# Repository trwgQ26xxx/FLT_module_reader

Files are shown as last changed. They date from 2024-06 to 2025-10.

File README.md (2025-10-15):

# Fiat Lancia Tester \ Alfa Romeo Tester \ Check Up 1 module reader

Dedicated module reader for FLT\ART\CU-1 ROMs archiving.

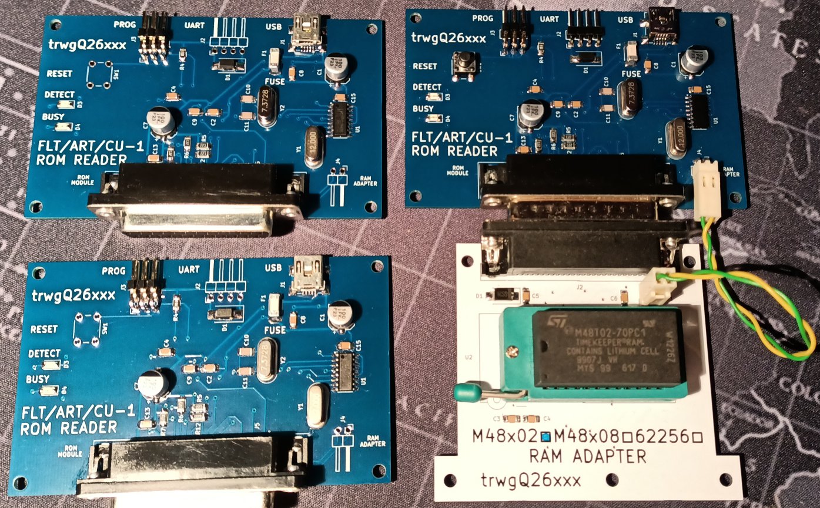
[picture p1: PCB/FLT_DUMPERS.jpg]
FLT_DUMPERS

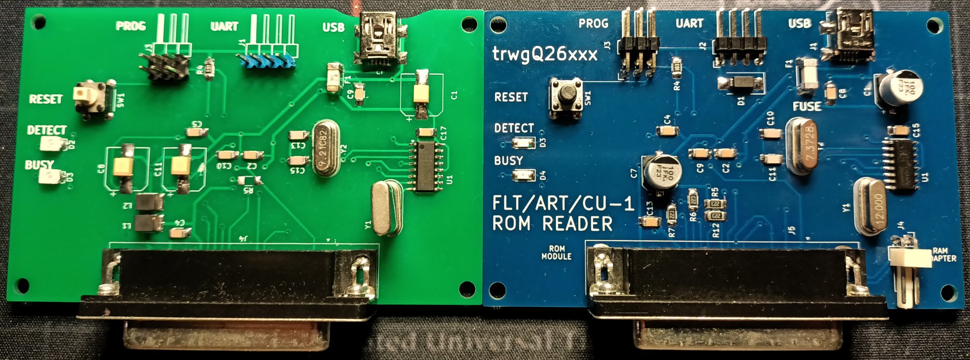
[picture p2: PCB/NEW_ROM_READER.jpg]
NEW_ROM_READER


# Disclaimer

I do not consent to the use of all or part of the project for commercial purposes!

Nie wyrażam zgody na wykorzystanie całości bądź części projektu w celach zarobkowych!

# License

Shield: [][cc-by-nc-sa]

This work is licensed under a
[Creative Commons Attribution-NonCommercial-ShareAlike 4.0 International License][cc-by-nc-sa].

[][cc-by-nc-sa]

[cc-by-nc-sa]: http://creativecommons.org/licenses/by-nc-sa/4.0/
[cc-by-nc-sa-image]: https://licensebuttons.net/l/by-nc-sa/4.0/88x31.png
[cc-by-nc-sa-shield]: https://img.shields.io/badge/License-CC%20BY--NC--SA%204.0-lightgrey.svg

# Directories organization

- **firmware** - MCU firmware, written in C.
- **pc_software** - PC software, written in Python.
- **PCB** - PCB project, prepared in KiCad version 8.0.1.
- **DS** - data sheets of used components

# Usage

| Windows | Linux | macOS |
| --- | --- | --- |
| reader COM[number] | ./reader /dev/ttyUSB[number] | ./reader /dev/wchusbserial[number] |

For example:

| Windows | Linux | macOS |
| --- | --- | --- |
| reader COM1 | ./reader /dev/ttyUSB0 | ./reader /dev/wchusbserial300 |

where */dev/wchusbserial300* (on macOS), */dev/ttyUSB0* (on Linux) or *COM1* (on Windows) should be actual serial port name of connected ROM reader.

# Basic instructions

1. (optional step) *search_ports* script can be used to identify ROM reader serial port name.

The ROM reader uses the CH340 serial chip, which can be identified by the VID/PID values of 1A86/7523, respectively.

SEARCH_PORTS

2. Connect the ROM reader to the PC. Running the program on a PC without a connected module will result in an error.

NO_MODULE

NO_MODULE_WIN

3. If a module is connected, the reader detects which ROMs are present in the connected module. In this example, we have a module with all three (**ROM A, B, and C**). If at least one ROM is installed (which will always be the case, since ROM B must be present), the program will prompt you to enter a prefix for the files that will be saved on the PC. I entered *M99A_IT* as an example. After confirming by pressing Enter, the ROM data dumping process begins:

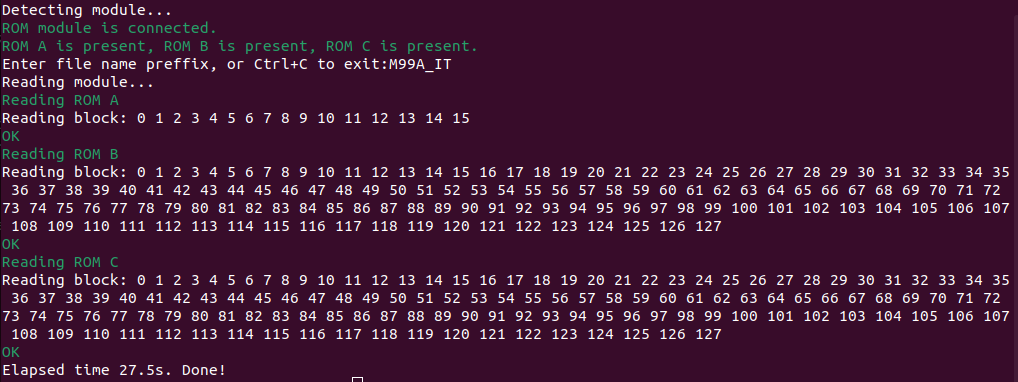
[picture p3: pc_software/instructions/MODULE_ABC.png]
MODULE_ABC


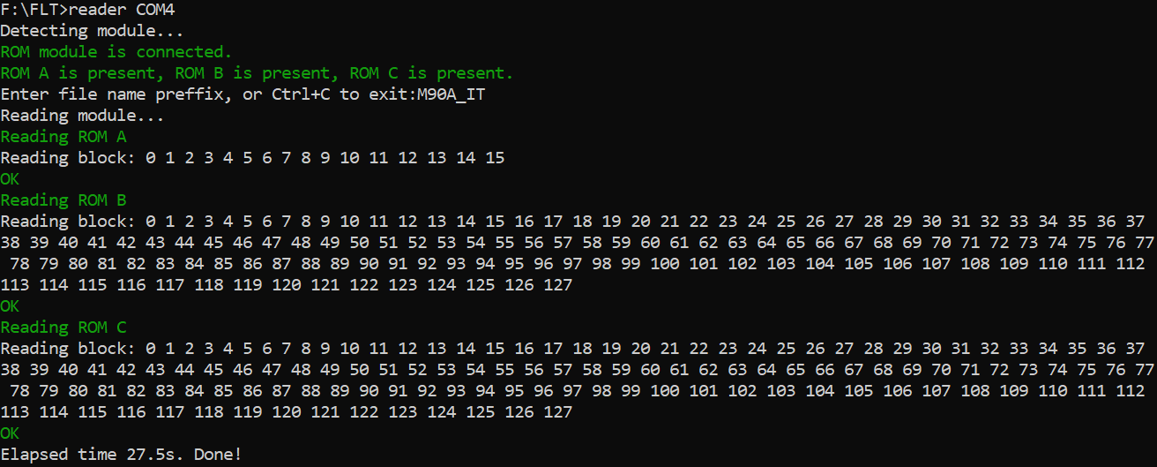
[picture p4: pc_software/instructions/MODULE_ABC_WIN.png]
MODULE_ABC_WIN


4. Data integrity is continuously checked using CRC while downloading individual blocks (each block is 512 bytes). **In most cases, it may be advisable to repeat the dumping operation twice, disconnecting and reconnecting the ROM module to clean the contacts slightly.** Finally, individual files containing the ROM data are saved to the PC:

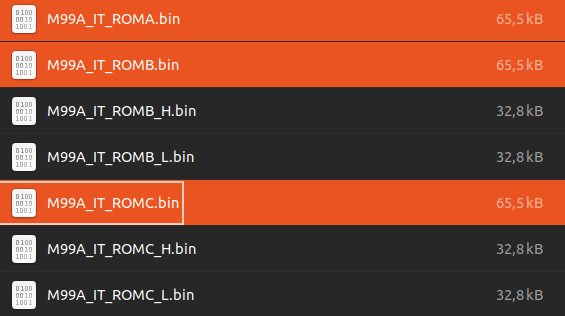
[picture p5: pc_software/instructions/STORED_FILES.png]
STORED_FILES


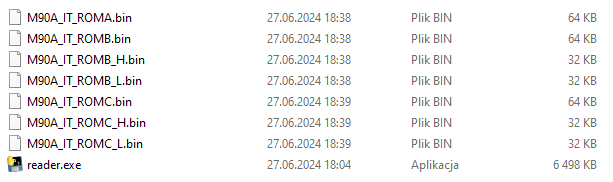
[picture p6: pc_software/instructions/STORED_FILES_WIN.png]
STORED_FILES_WIN


The process is similar for other modules. Here is an example if the module contains only **ROM A and B**:

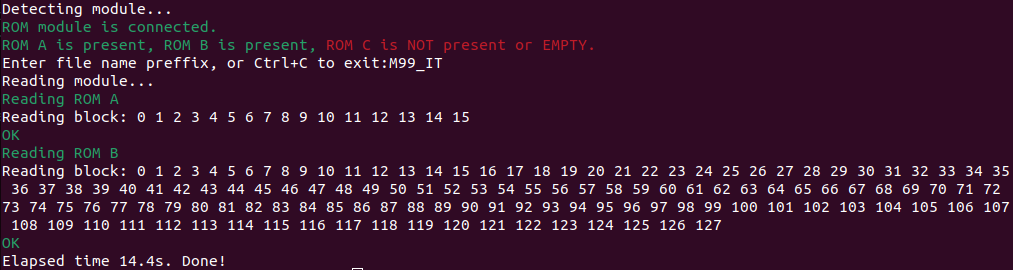
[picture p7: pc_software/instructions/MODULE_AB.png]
MODULE_AB


or **ROM B** only:

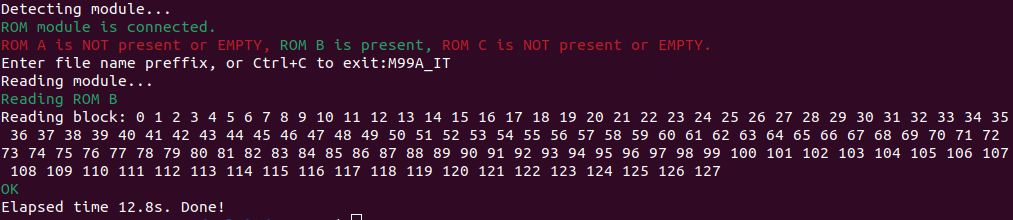
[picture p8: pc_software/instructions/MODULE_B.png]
MODULE_ABC


The program reads the contents of only the ROMs that are present in the module.

# RAM adapter

The RAM adapter is used for SRAM testing. It was primarily constructed to test the M48Z02 (used in FLT/ART) and the M48T02 (used in CU-1). The RAM adapter takes the form of a standard FLT ROM module. Additionally, it requires a connection to a supplementary 2-pin connector with the #WR signal, which is not present on the DSUB-25 connector of the ROM.

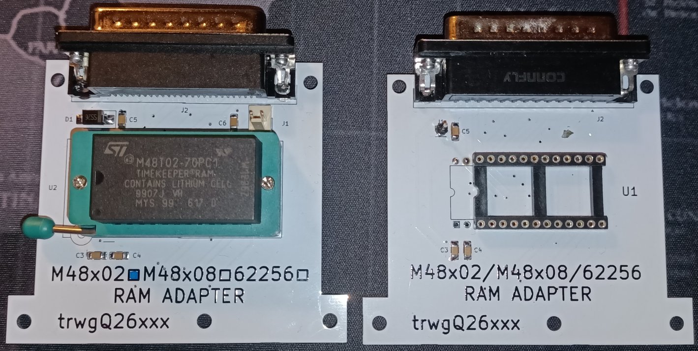
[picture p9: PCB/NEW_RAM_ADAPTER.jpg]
NEW_RAM_ADAPTER


Before usage, the RAM adapter must be configured to the correct RAM variant using solder bridges (SB1 - SB3) on the PCB. The configuration is as follows:

| RAM | Size | SB1 | SB2 | SB3 |
| --- | ---- | --- | --- | --- |
| M48T02, M48T12, M48Z02 and M48Z12 | 2kB | OFF | 1-2 | 1-2 |
| M48T08, M48T18, M48Z08 and M48Z18 | 8kB | OFF | 1-2 | 2-3 |
| 62256 | 32kB | ON | 2-3 | 2-3 |

The supported commands are:

* *RAM_test ram_type serial_port*, for example: ./RAM_test M48T02 /dev/ttyUSB0

This command tests the SRAM battery and SRAM memory. The supported SRAM types (*ram_type*) for this command are:

| *ram_type* | Size | Type |
| --- | --- | --- |
| M48T02 | 2kB | battery-backed SRAM with RTC |
| M48Z02 | 2kB | battery-backed SRAM |
| M48T08 | 8kB | battery-backed SRAM with RTC |
| M48Z08 | 8kB | battery-backed SRAM |
| S62256 | 32kB | SRAM |

RAM_TEST

* *RAM_clock_cmd ram_type command serial_port*, for example ./RAM_clock_cmd M48T02 set /dev/ttyUSB0

Executes an RTC-specific command. The command (*command*) can be:

| *command* | Description |
| --- | --- |
| start | Starts the internal oscillator and enables normal clock operation. |
| stop | Stops the internal oscillator, which saves battery power if the SRAM is left on the shelf for an extended period. |
| set | Sets the current time. |
| reset | Resets all registers, stops the internal oscillator, and sets the time to 0:0:0 on 1-1-2000. |

The supported SRAM types for this command are:

| *ram_type* | Size | Type |
| --- | --- | --- |
| M48T02 | 2kB | battery-backed SRAM with RTC |
| M48T08 | 8kB | battery-backed SRAM with RTC |

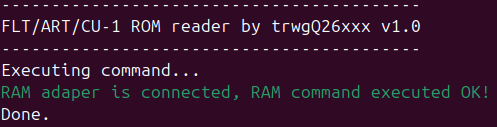
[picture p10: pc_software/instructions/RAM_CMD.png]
RAM_CMD


* *RAM_clock_read ram_type serial_port*, for example ./RAM_clock_read M48T02 /dev/ttyUSB0

Retrieves the time from the SRAM RTC and prints it on the screen in an infinite loop at a rate of twice per second. Use Ctrl-C to stop the execution of this command.

The supported SRAM types for this command are:

| *ram_type* | Size | Type |
| --- | --- | --- |
| M48T02 | 2kB | battery-backed SRAM with RTC |
| M48T08 | 8kB | battery-backed SRAM with RTC |

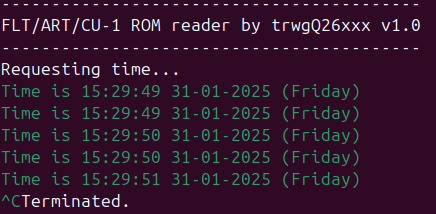
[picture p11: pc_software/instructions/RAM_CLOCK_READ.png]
RAM_CLOCK_READ


# Complete procedure to test battery-backed RAM

1. Use *RAM_test* to check the RAM battery and RAM memory cells.
2. If the RAM has an RTC:

- Execute the *reset command* to reset the RAM clock.

- Execute the *start command** to starts the internal oscillator and enable normal clock operation.

- Execute the *set command* to set the current time.

- Run *RAM_clock_read* to verify both the validity of the time and that it increments. If both conditions are met, the RTC is functioning properly.

# Notes

Atmega64A fusebits should be configured as follows:

| Extended | High | Low |
| --- | --- | --- |
| 0xFE | 0xC9 | 0x1F |

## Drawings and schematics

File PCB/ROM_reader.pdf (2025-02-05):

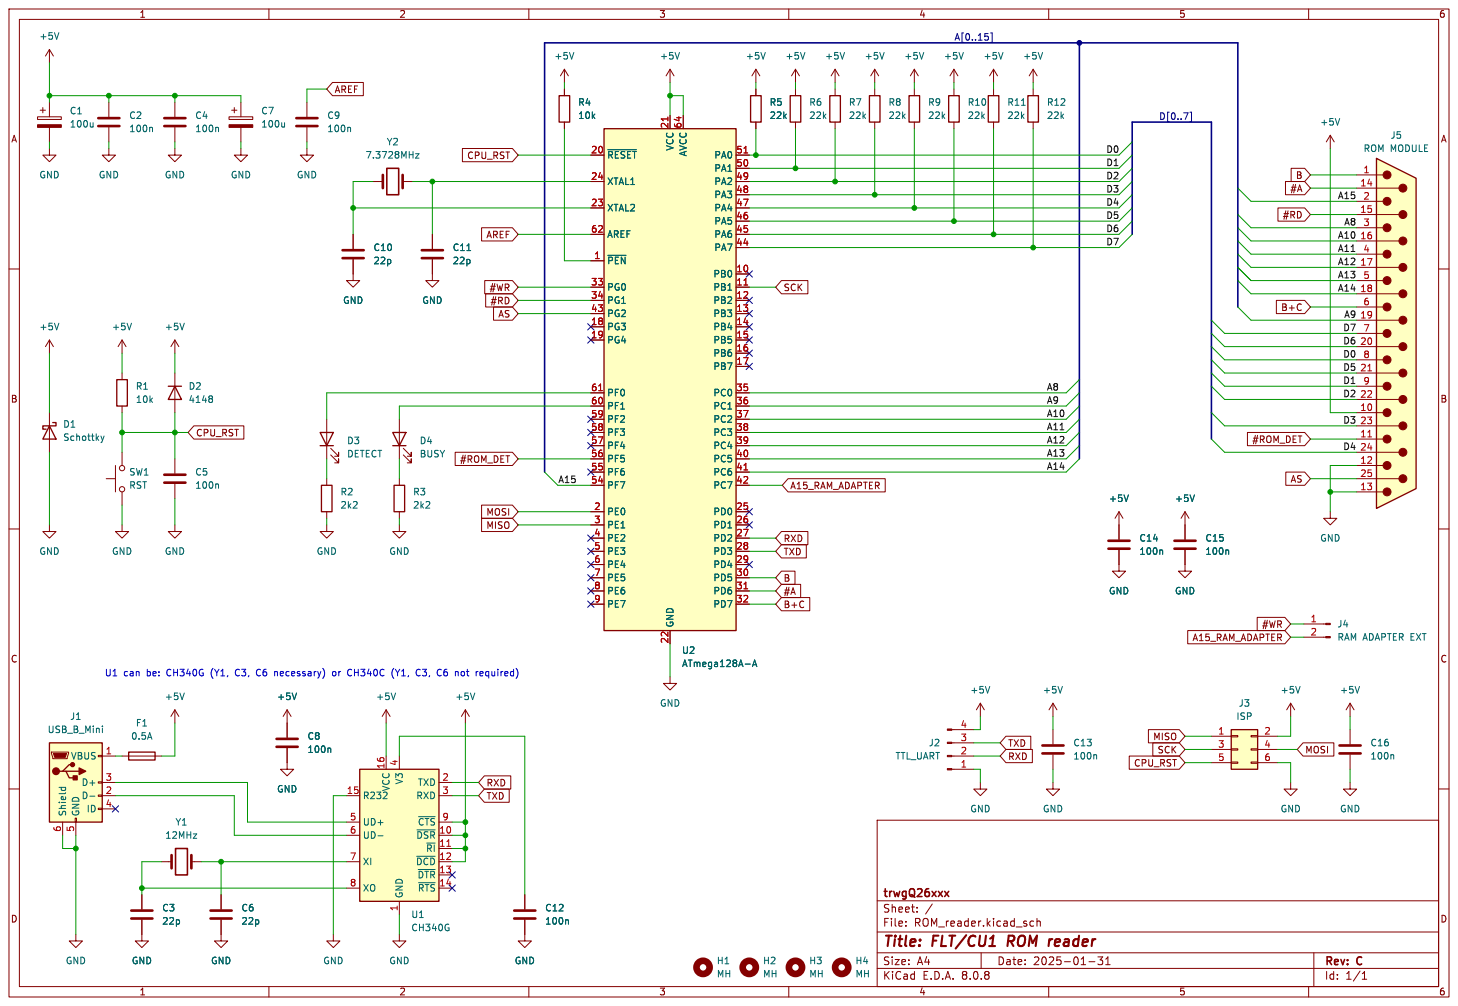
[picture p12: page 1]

1 ~{DSR} 10 ~{RI} 11 ~{DCD} 12 ~{DTR} 13 ~{RTS} 14 R232 15 VCC 16 TXD 2 RXD 3 V3

4 UD+ 5 UD- 6 XI 7 XO 8 ~{CTS}9 U1 CH340G

Id: 1/1 Title: FLT/CU1 ROM reader File: ROM_reader.kicad_sch Sheet: / trwgQ26xxx Y1

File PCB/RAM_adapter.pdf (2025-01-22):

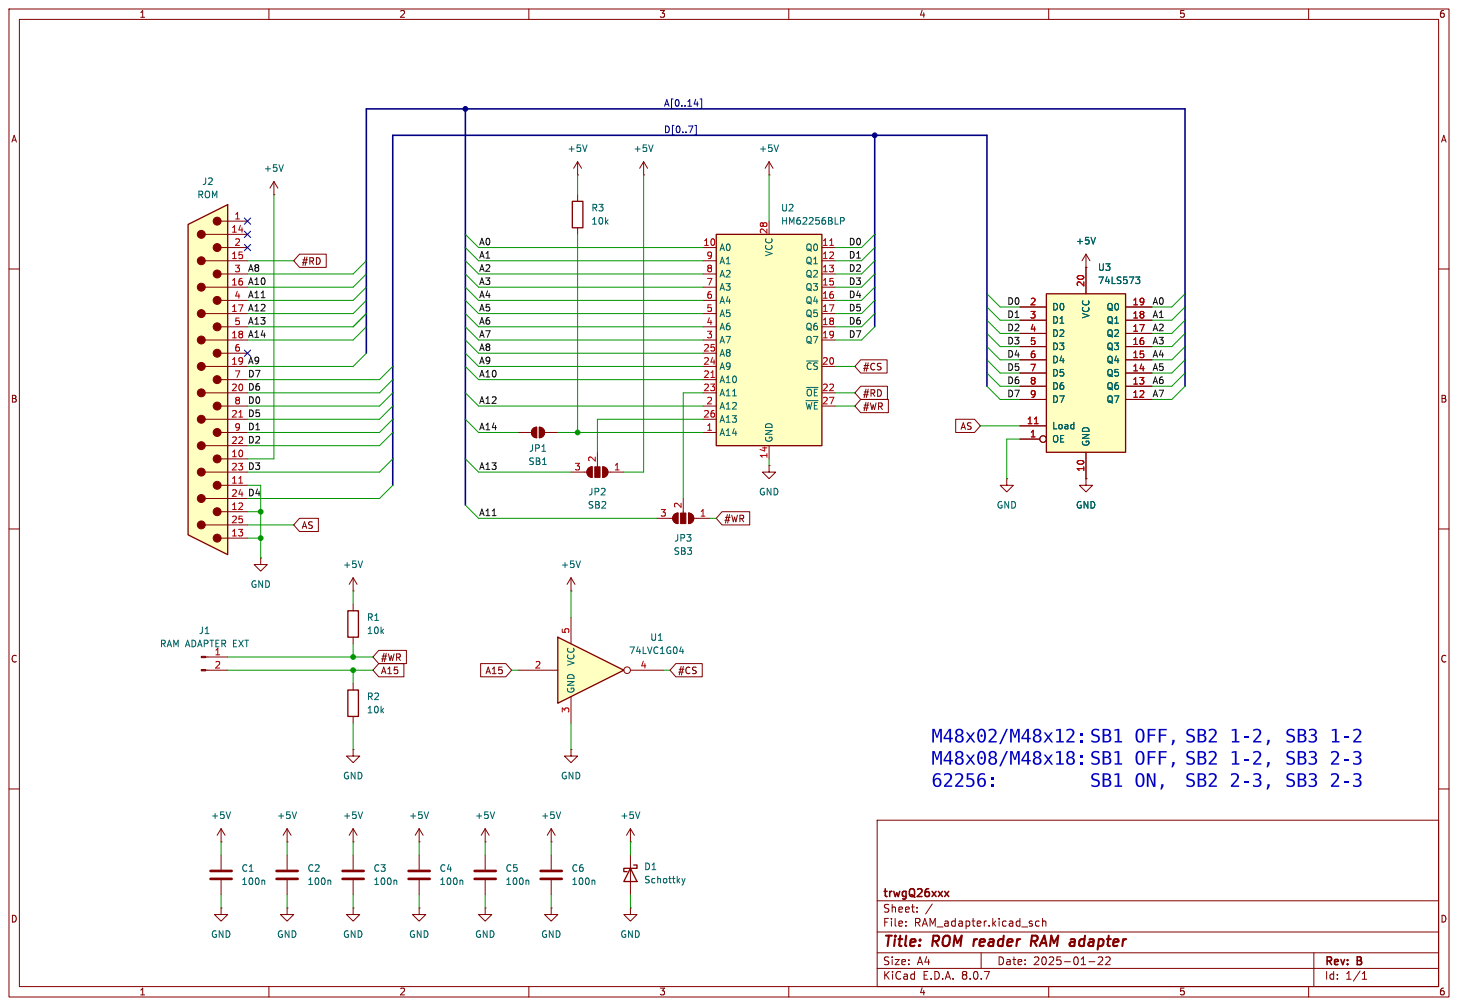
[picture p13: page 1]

Id: 1/1 Title: ROM reader RAM adapter File: RAM_adapter.kicad_sch Sheet: / trwgQ26xxx C6

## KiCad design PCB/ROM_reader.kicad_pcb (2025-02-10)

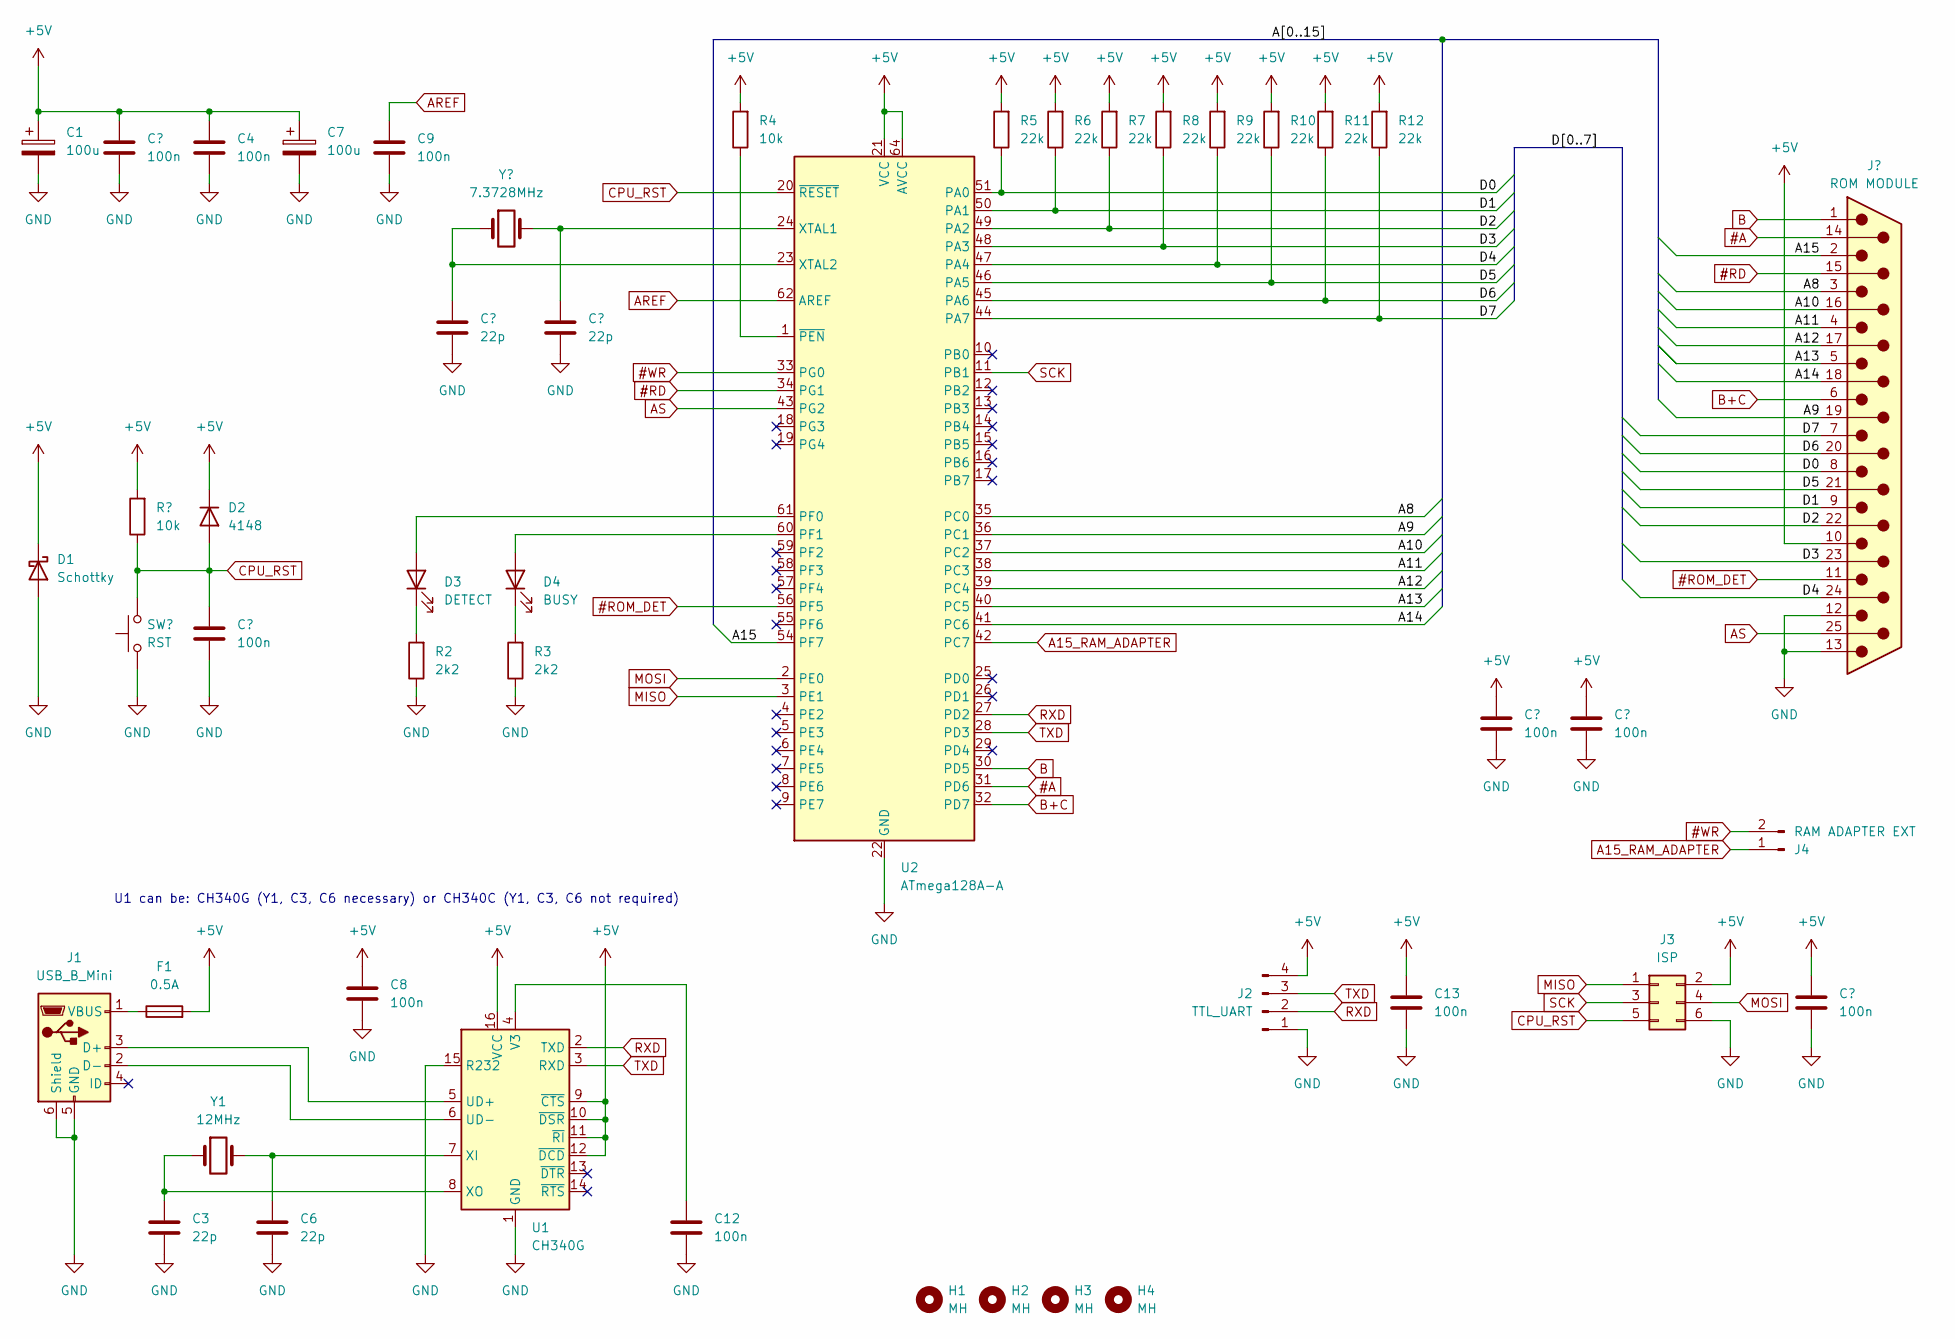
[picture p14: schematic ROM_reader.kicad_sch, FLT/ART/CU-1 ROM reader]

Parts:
C1, C7: 100u; CP_Elec_6.3x7.7
C2, C4, C5, C8, C9, C12, C13, C14, C15, C16: 100n; C_1206_3216Metric_Pad1.33x1.80mm_HandSolder
C3, C6, C10, C11: 22p; C_1206_3216Metric_Pad1.33x1.80mm_HandSolder
D1: Schottky; D_SMB_Handsoldering
D2: 4148; D_SMA_Handsoldering
D3: DETECT; LED_1206_3216Metric_Pad1.42x1.75mm_HandSolder
D4: BUSY; LED_1206_3216Metric_Pad1.42x1.75mm_HandSolder
F1: 0.5A; Fuse_2512_6332Metric_Pad1.52x3.35mm_HandSolder
H1, H2, H3, H4: MH; MountingHole_3.2mm_M3_DIN965
J1: USB_B_Mini; USB_Mini-B_Wuerth_65100516121_Horizontal
J2: TTL_UART; PinHeader_1x04_P2.54mm_Horizontal
J3: ISP; PinHeader_2x03_P2.54mm_Horizontal
J4: RAM ADAPTER EXT; PinHeader_1x02_P2.54mm_Horizontal
J5: ROM MODULE; DSUB-25_Female_Horizontal_P2.77x2.84mm_EdgePinOffset4.94mm_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
R1, R4: 10k; R_1206_3216Metric_Pad1.30x1.75mm_HandSolder
R2, R3: 2k2; R_1206_3216Metric_Pad1.30x1.75mm_HandSolder
R5, R6, R7, R8, R9, R10, R11, R12: 22k; R_1206_3216Metric_Pad1.30x1.75mm_HandSolder
SW1: RST; SW_PUSH_6mm
U1: CH340G; SOIC-16_3.9x9.9mm_P1.27mm
U2: ATmega128A-A; TQFP-64_14x14mm_P0.8mm
Y1: 12MHz; Crystal_HC49-4H_Vertical
Y2: 7.3728MHz; Crystal_HC49-4H_Vertical

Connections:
#A: J5.14, U2.31 (PD6)
#RD: J5.15, U2.34 (PG1)
#ROM_DET: J5.11, U2.56 (PF5)
#WR: J4.2, U2.33 (PG0)
+5V: C1.1, C2.1, C4.1, C7.1, C8.1, C13.1, C14.1, C15.1, C16.1, D1.1 (K), D2.1 (K), F1.2, J2.4, J3.2, J5.10, R1.2, R4.2, R5.2, R6.2, R7.2, R8.2, R9.2, R10.2, R11.2, R12.2, U1.9 (~CTS), U1.10 (~DSR), U1.11 (~RI), U1.12 (~DCD), U1.16 (VCC), U2.21 (VCC), U2.52 (VCC), U2.64 (AVCC)
/A8: J5.3, U2.35 (PC0)
/A9: J5.19, U2.36 (PC1)
/A10: J5.16, U2.37 (PC2)
/A11: J5.4, U2.38 (PC3)
/A12: J5.17, U2.39 (PC4)
/A13: J5.5, U2.40 (PC5)
/A14: J5.18, U2.41 (PC6)
/A15: J5.2, U2.54 (PF7)
/D0: J5.8, R5.1, U2.51 (PA0)
/D1: J5.9, R6.1, U2.50 (PA1)
/D2: J5.22, R7.1, U2.49 (PA2)
/D3: J5.23, R8.1, U2.48 (PA3)
/D4: J5.24, R9.1, U2.47 (PA4)
/D5: J5.21, R10.1, U2.46 (PA5)
/D6: J5.20, R11.1, U2.45 (PA6)
/D7: J5.7, R12.1, U2.44 (PA7)
A15_RAM_ADAPTER: J4.1, U2.42 (PC7)
AREF: C9.1, U2.62 (AREF)
AS: J5.25, U2.43 (PG2)
B: J5.1, U2.30 (PD5)
B+C: J5.6, U2.32 (PD7)
CPU_RST: C5.1, D2.2 (A), J3.5, R1.1, SW1.2, U2.20 (~RESET)
GND: C1.2, C2.2, C3.2, C4.2, C5.2, C6.2, C7.2, C8.2, C9.2, C10.2, C11.2, C12.2, C13.2, C14.2, C15.2, C16.2, D1.2 (A), J1.5 (GND), J1.6 (Shield), J2.1, J3.6, J5.0, J5.12, J5.13, R2.1, R3.1, SW1.1, U1.1 (GND), U1.15 (R232), U2.22 (GND), U2.53 (GND), U2.63 (GND)
MISO: J3.1, U2.3 (PE1)
MOSI: J3.4, U2.2 (PE0)
unnamed: D3.2 (A), U2.61 (PF0)
unnamed: D3.1 (K), R2.2
unnamed: D4.2 (A), U2.60 (PF1)
unnamed: D4.1 (K), R3.2
unnamed: J1.3 (D+), U1.5 (UD+)
unnamed: J1.2 (D-), U1.6 (UD-)
unnamed: F1.1, J1.1 (VBUS)
unnamed: C12.1, U1.4 (V3)
unnamed: C6.1, U1.7 (XI), Y1.2
unnamed: C3.1, U1.8 (XO), Y1.1
unnamed: C11.1, U2.24 (XTAL1), Y2.2
unnamed: C10.1, U2.23 (XTAL2), Y2.1
unnamed: R4.1, U2.1 (~PEN)
RXD: J2.2, U1.2 (TXD), U2.27 (PD2)
SCK: J3.3, U2.11 (PB1)
TXD: J2.3, U1.3 (RXD), U2.28 (PD3)

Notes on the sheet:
U1 can be: CH340G (Y1, C3, C6 necessary) or CH340C (Y1, C3, C6 not required)

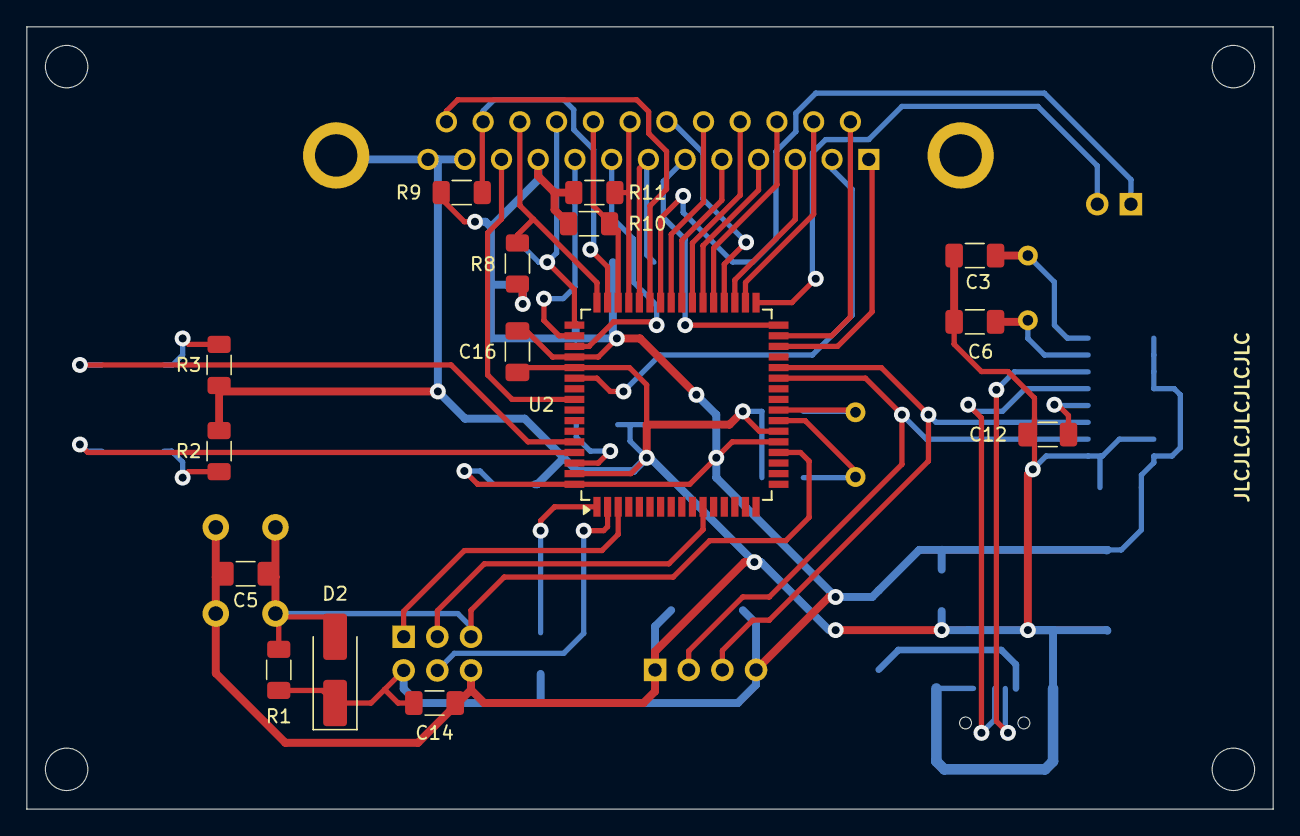
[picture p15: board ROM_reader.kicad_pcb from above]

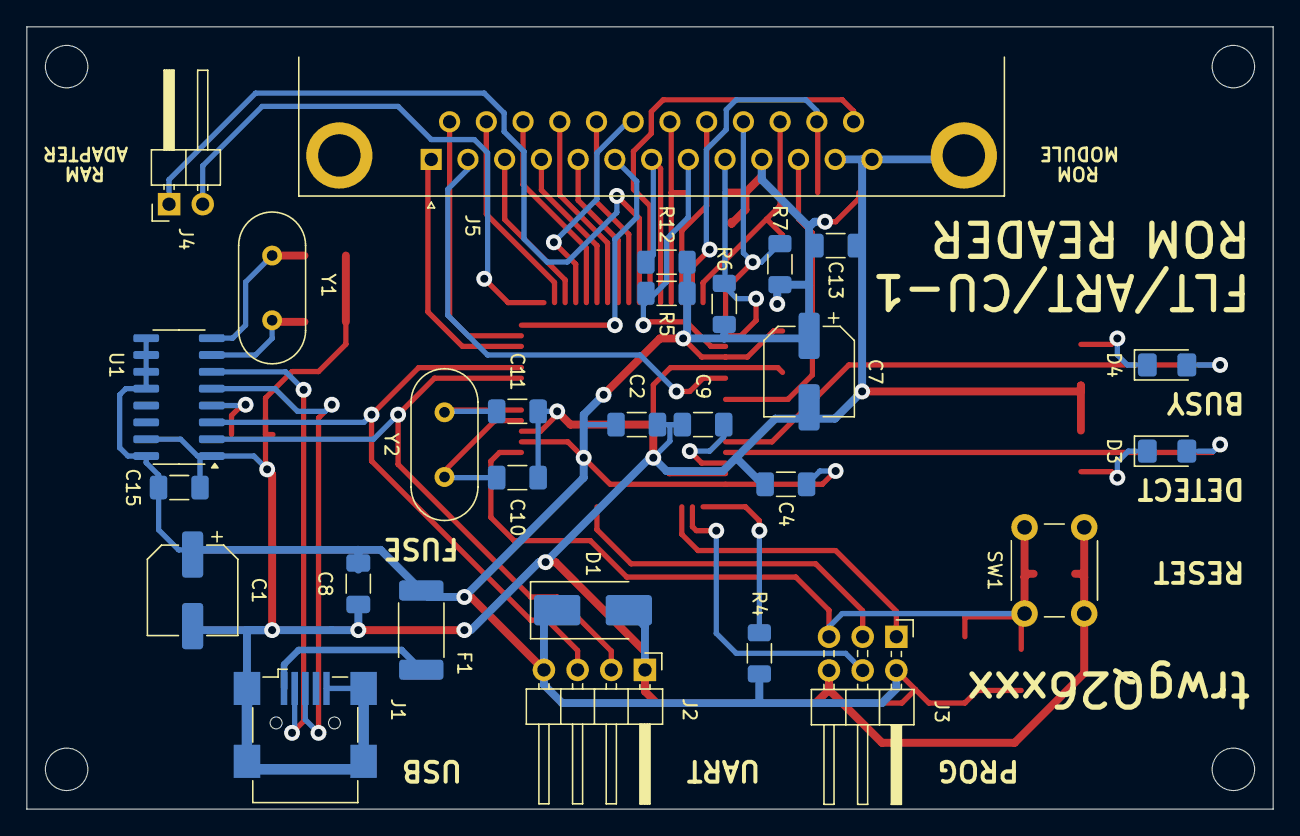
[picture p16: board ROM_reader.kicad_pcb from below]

Board: 2 copper layers, 94.0 x 59.0 mm, 47 parts (28 on the bottom side), 46 nets.

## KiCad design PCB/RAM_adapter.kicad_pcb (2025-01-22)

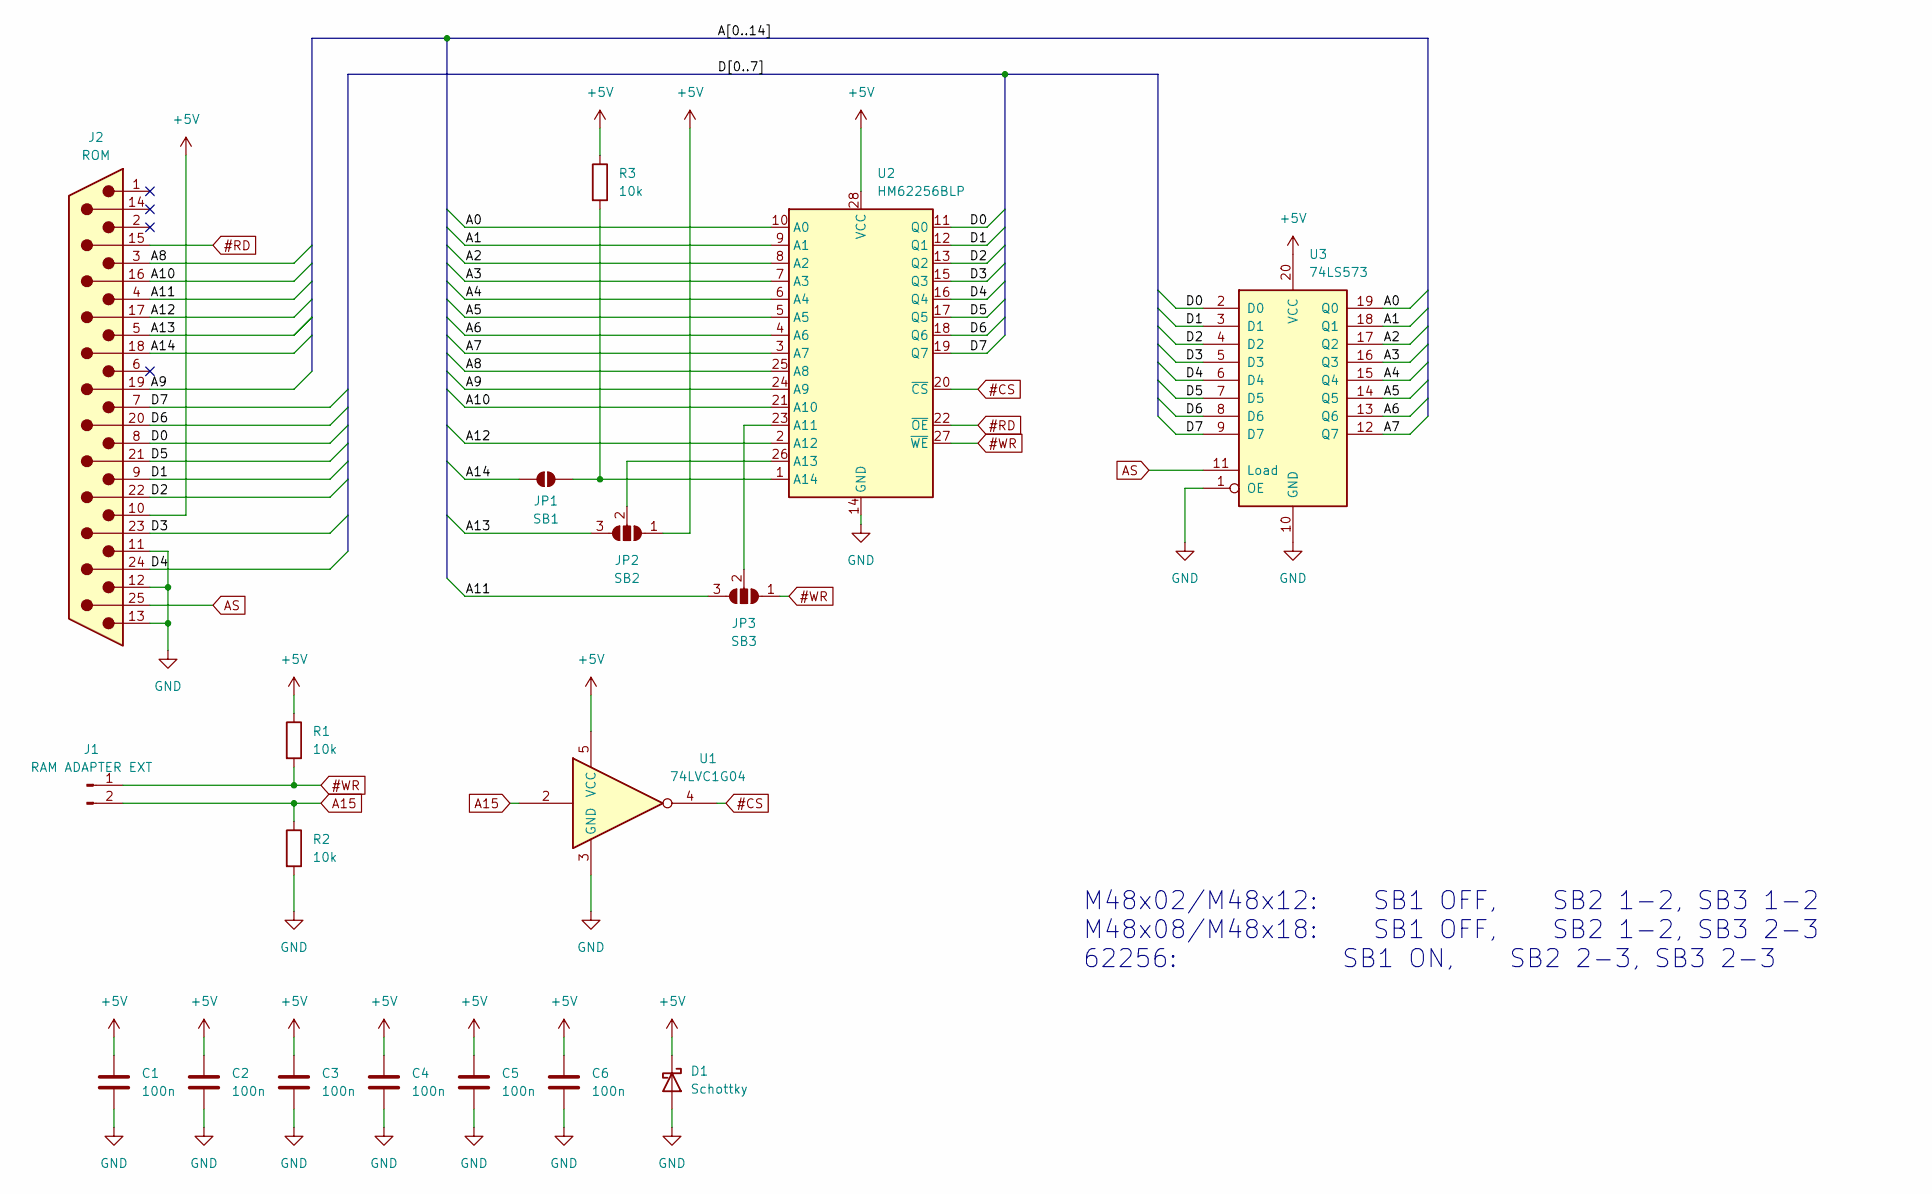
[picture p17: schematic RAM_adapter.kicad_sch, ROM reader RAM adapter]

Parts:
C1, C2, C3, C4, C5, C6: 100n; C_1206_3216Metric_Pad1.33x1.80mm_HandSolder
D1: Schottky; D_SMB_Handsoldering
J1: RAM ADAPTER EXT; PinHeader_1x02_P2.54mm_Vertical
J2: ROM; DSUB-25_Male_Horizontal_P2.77x2.84mm_EdgePinOffset4.94mm_Ho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
JP1: SB1; SolderJumper-2_P1.3mm_Open_RoundedPad1.0x1.5mm
JP2: SB2; SolderJumper-3_P1.3mm_Open_RoundedPad1.0x1.5mm
JP3: SB3; SolderJumper-3_P1.3mm_Open_RoundedPad1.0x1.5mm
R1, R2, R3: 10k; R_1206_3216Metric_Pad1.30x1.75mm_HandSolder
U1: 74LVC1G04; SOT-23-5_HandSoldering
U2: HM62256BLP; DIP_Socket-28_W11.9_W12.7_W15.24_W17.78_W18.5_3M_228-1277-0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
U3: 74LS573; SOIC-20W_7.5x12.8mm_P1.27mm

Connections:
#CS: U1.4, U2.20 (~CS)
#RD: J2.15, U2.22 (~OE)
#WR: J1.1, JP3.1 (A), R1.2, U2.27 (~WE)
+5V: C1.1, C2.1, C3.1, C4.1, C5.1, C6.1, D1.1 (K), J2.10, JP2.1 (A), R1.1, R3.1, U1.5 (VCC), U2.28 (VCC), U3.20 (VCC)
/A0: U2.10 (A0), U3.19 (Q0)
/A1: U2.9 (A1), U3.18 (Q1)
/A2: U2.8 (A2), U3.17 (Q2)
/A3: U2.7 (A3), U3.16 (Q3)
/A4: U2.6 (A4), U3.15 (Q4)
/A5: U2.5 (A5), U3.14 (Q5)
/A6: U2.4 (A6), U3.13 (Q6)
/A7: U2.3 (A7), U3.12 (Q7)
/A8: J2.3, U2.25 (A8)
/A9: J2.19, U2.24 (A9)
/A10: J2.16, U2.21 (A10)
/A11: J2.4, JP3.3 (B)
/A12: J2.17, U2.2 (A12)
/A13: J2.5, JP2.3 (B)
/A14: J2.18, JP1.2 (B)
/D0: J2.8, U2.11 (Q0), U3.2 (D0)
/D1: J2.9, U2.12 (Q1), U3.3 (D1)
/D2: J2.22, U2.13 (Q2), U3.4 (D2)
/D3: J2.23, U2.15 (Q3), U3.5 (D3)
/D4: J2.24, U2.16 (Q4), U3.6 (D4)
/D5: J2.21, U2.17 (Q5), U3.7 (D5)
/D6: J2.20, U2.18 (Q6), U3.8 (D6)
/D7: J2.7, U2.19 (Q7), U3.9 (D7)
A15: J1.2, R2.1, U1.2
AS: J2.25, U3.11 (Load)
GND: C1.2, C2.2, C3.2, C4.2, C5.2, C6.2, D1.2 (A), J2.11, J2.12, J2.13, R2.2, U1.3 (GND), U2.14 (GND), U3.1 (OE), U3.10 (GND)
unnamed: JP1.1 (A), R3.2, U2.1 (A14)
unnamed: JP2.2 (C), U2.26 (A13)
unnamed: JP3.2 (C), U2.23 (A11)

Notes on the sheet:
M48x02/M48x12: SB1 OFF, SB2 1-2, SB3 1-2 M48x08/M48x18: SB1 OFF, SB2 1-2, SB3 2-3 62256: SB1 ON, SB2 2-3, SB3 2-3

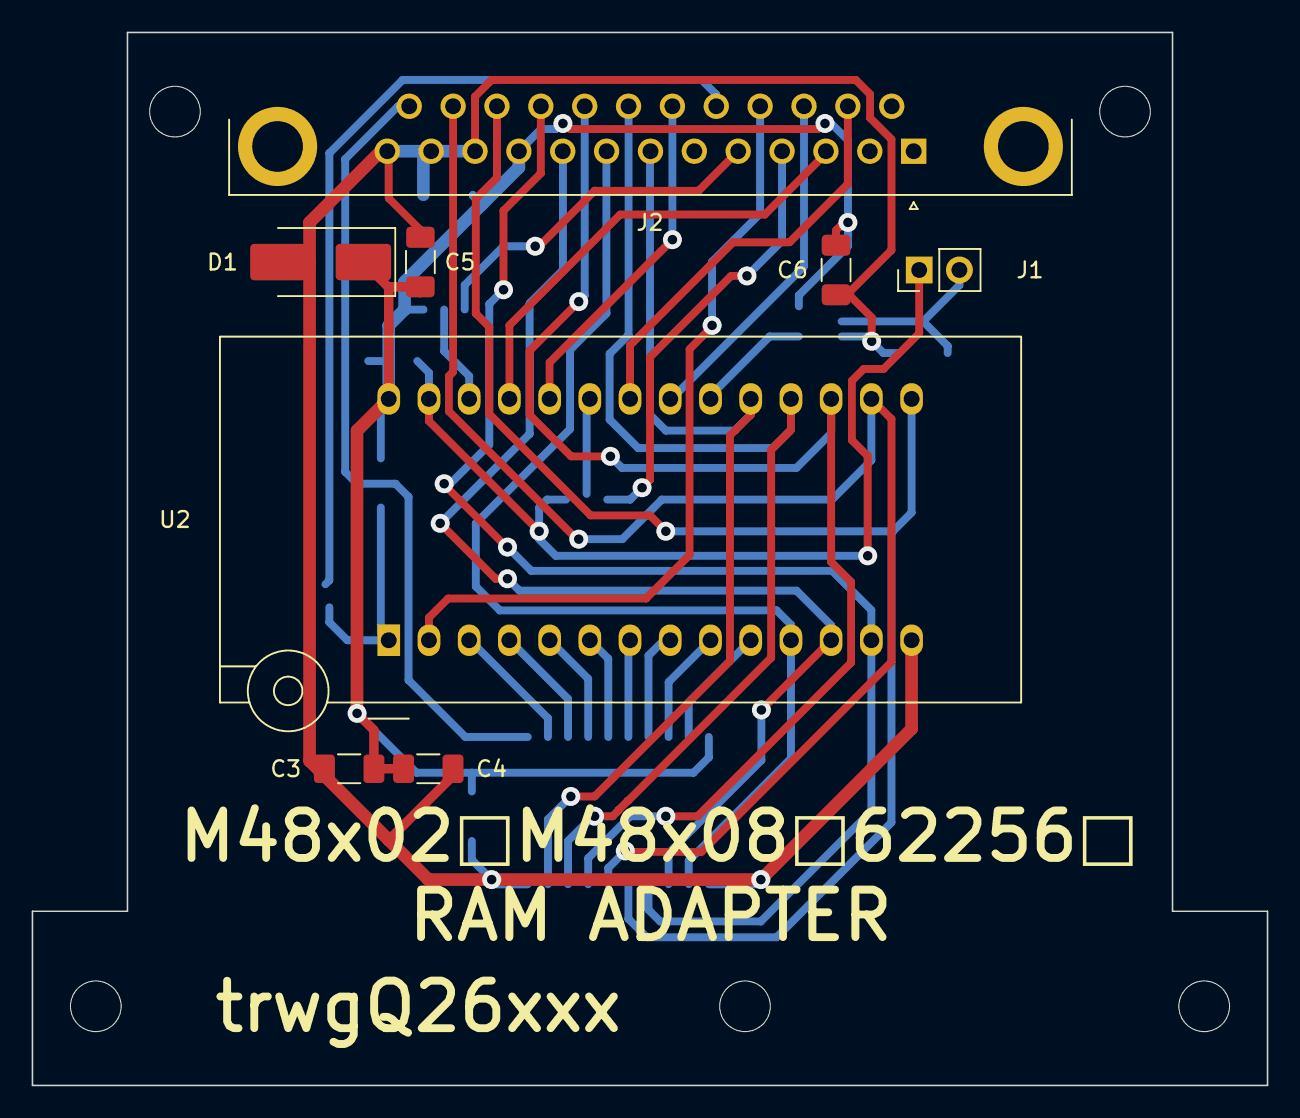
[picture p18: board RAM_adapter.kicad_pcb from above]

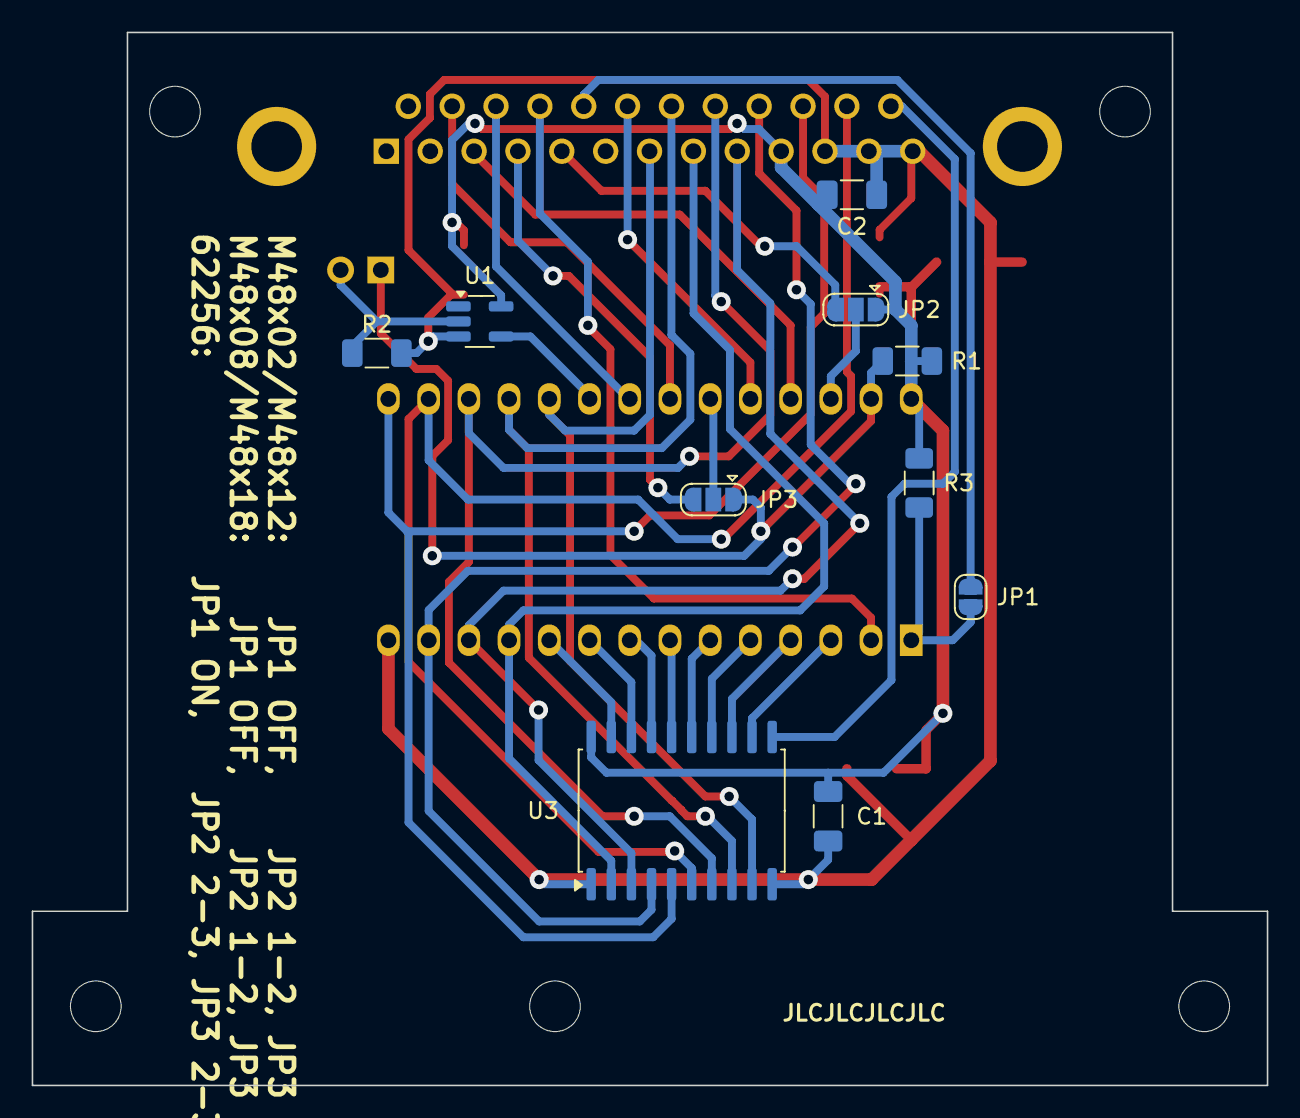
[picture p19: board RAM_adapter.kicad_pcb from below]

Board: 2 copper layers, 78.0 x 66.5 mm, 18 parts (10 on the bottom side), 33 nets.

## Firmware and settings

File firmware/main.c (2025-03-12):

/* 
Project name:	FLT/ART/CU1 ROM Reader
Author: 		trwgQ26xxx
Date:			26.06.2024
Target MCUs:	ATmega64/ATmega64L/ATmega64A/ATmega128/ATmega128L/ATmega128A
Compiler:		AVR-GCC version 7.3.0
*/

#include <stdint.h>
#include <string.h>

#include "common_definitions.h"

#include "drv/hw_ext_mem.h"
#include "drv/hw_uart.h"
#include "drv/hw_rom_switching.h"
#include "drv/hw_leds.h"
#include "drv/hw_tmr.h"
#include "drv/hw_wdt.h"

#include "serial_transmission.h"


volatile uint8_t module_detection_was_performed 	= FALSE;
volatile uint8_t module_is_connected 				= FALSE;

volatile uint8_t ROM_A_is_present = ROM_NOT_PRESENT;
volatile uint8_t ROM_B_is_present = ROM_NOT_PRESENT;
volatile uint8_t ROM_C_is_present = ROM_NOT_PRESENT;

volatile uint8_t RAM_battery_is_OK = FALSE;
volatile uint8_t RAM_memory_is_OK = FALSE;

static uint8_t rx_cmd_buffer[RX_CMD_BUFFER_MAX_LEN], rx_cmd_len = 0;
static uint8_t tx_response_buffer[TX_BUFFER_MAX_LEN];


inline uint8_t Select_correct_bank_for_A_ROM(uint8_t block_number, uint8_t *block_to_read);
inline uint8_t Select_correct_bank_for_B_and_C_ROMs(uint8_t block_number, uint8_t *block_to_read);
inline void Clear_ROM_info(void);
inline uint8_t Check_8K_ROM(void);
inline uint8_t Check_32K_ROM(void);
inline uint8_t Check_64K_ROMs(void);

void RomDetection(void);
void RomRead(void);

void RamTest(void);

void ControlRamClock(void);
void GetRamClock(void);
void SetRamClock(void);


int main(void)
{
	/* Set WDT to correct timeout, as */
	/* it is always enabled via fuse bit */
	Init_WDT();
	
	/* Initialize peripherals */
    Init_EXTMEM();
    Init_LEDs();
    Init_ROMs();
    Init_UART(BAUDRATE);
    Init_TMR(TMR_PERIOD);
    Init_unused_pins();

    /* Enable IRQs */
    sei();

    /* Prepare UART reception */
    Reset_RX_Transmission();

    /* Clear variables */
    Clear_ROM_info();

    /* Disable auto detect */
	SET_A15_TO_HIGH;
	CONFIGURE_A15_AS_OUT;
	
	/* Clear WDT */
	Poke_WDT();

    /* Main loop */
    while(1)
    {
		switch(Process_RX_Transmission(rx_cmd_buffer, &rx_cmd_len))
		{
		case DETECT_COMMAND:
			RomDetection();
			break;

		case READ_COMMAND:
			RomRead();
			break;

		case RAMTEST_COMMAND:
			RamTest();
			break;

		case CONTROL_RAM_CLOCK_COMMAND:
			ControlRamClock();
			break;

		case GET_RAM_CLOCK_COMMAND:
			GetRamClock();
			break;

		case SET_RAM_CLOCK_COMMAND:
			SetRamClock();
			break;

		default:
			/* Nothing */
			break;
		}
		
		/* Clear WDT */
		Poke_WDT();
    }

    /* Program should never go here */
    return 0;
}

/* ROM_DETECTION_CODE */
void RomDetection(void)
{
	/* Check command length */
	if(rx_cmd_len == DETECT_CMD_LEN)
	{
		BUSY_LED_ON;

		/* Perform detection only if module is connected */
		if(module_is_connected == TRUE)
		{
			SET_A15_TO_HIGH;
			CONFIGURE_A15_AS_OUT;

			/* Check ROM A */
			ENABLE_A_ROM;
			ROM_A_is_present = Check_8K_ROM();

			/* Check ROM B */
			ENABLE_B_ROM;
			ROM_B_is_present = Check_64K_ROMs();

			/* Check ROM C */
			ENABLE_C_ROM;
			ROM_C_is_present = Check_64K_ROMs();

			SET_A15_TO_HIGH;
			DISABLE_ALL_ROMS;

			module_detection_was_performed = 1;
		}

		/* Compose response */
		tx_response_buffer[CMD_INDEX]		= DETECT_COMMAND;
		tx_response_buffer[DETECT_INDEX]	= module_is_connected;
		tx_response_buffer[A_SIZE_INDEX]	= ROM_A_is_present;
		tx_response_buffer[B_SIZE_INDEX]	= ROM_B_is_present;
		tx_response_buffer[C_SIZE_INDEX]	= ROM_C_is_present;

		/* Send response to PC */
		TX_frame(tx_response_buffer, DETECT_CMD_RESPONSE_LEN);

		BUSY_LED_OFF;
	}

	return;
}

/* READ_ROM_CODE */
void RomRead(void)
{
	uint8_t data_valid = TRUE;
	uint8_t block_to_read = 0;

	/* Check command length */
	if(rx_cmd_len == READ_CMD_LEN)
	{
		BUSY_LED_ON;

		uint8_t rom_sel 		= rx_cmd_buffer[ROM_SEL_INDEX];
		uint8_t block_number 	= rx_cmd_buffer[BLOCK_NUMBER_INDEX];

		if((module_is_connected == TRUE) && (module_detection_was_performed == TRUE))
		{
			/* Select correct ROM */
			switch(rom_sel)
			{
			case ROM_TYPE_A:
				data_valid = Select_correct_bank_for_A_ROM(block_number, &block_to_read);

				ENABLE_A_ROM;
				break;

			case ROM_TYPE_B:
				data_valid = Select_correct_bank_for_B_and_C_ROMs(block_number, &block_to_read);

				ENABLE_B_ROM;
				break;

			case ROM_TYPE_C:
				data_valid = Select_correct_bank_for_B_and_C_ROMs(block_number, &block_to_read);

				ENABLE_C_ROM;
				break;

			default:
				/* Data invalid */
				data_valid = FALSE;

				/* Wrong ROM */
				DISABLE_ALL_ROMS;

				break;
			}

			/* Read data */
			Read_ROM_block(&tx_response_buffer[DATA_INDEX], block_to_read);
		}
		else
		{
			data_valid = FALSE;
		}

		/* Disable ROMs */
		DISABLE_ALL_ROMS;
		SET_A15_TO_HIGH;

		/* Compose response */
		tx_response_buffer[CMD_INDEX] 			= READ_COMMAND;
		tx_response_buffer[DATA_VALID_INDEX]	= data_valid;

		if(data_valid == FALSE)
		{
			/* Clear buffer if data is not valid */
			memset(&tx_response_buffer[DATA_INDEX], 0xFF, SINGLE_BLOCK_SIZE);
		}

		/* Send response to PC */
		TX_frame(tx_response_buffer, READ_CMD_RESPONSE_LEN);

		BUSY_LED_OFF;
	}

	return;
}

/* RAM_TEST_CODE */
void RamTest(void)
{
	/* Check command length */
	if(rx_cmd_len == RAMTEST_CMD_LEN)
	{
		BUSY_LED_ON;

		uint8_t ram_type = rx_cmd_buffer[RAM_TYPE_INDEX];

		/* Perform test only if module is connected */
		if(module_is_connected == TRUE)
		{
			/* Select correct RAM */
			switch(ram_type)
			{
				case M48T02_RAM_TYPE:

					RAM_battery_is_OK = Check_if_RAM_battery_is_OK();
					RAM_memory_is_OK = Check_if_RAM_memory_is_OK(M48T02_RAM_SIZE);

					break;

				case M48Z02_RAM_TYPE:

					RAM_battery_is_OK = Check_if_RAM_battery_is_OK();
					RAM_memory_is_OK = Check_if_RAM_memory_is_OK(M48Z02_RAM_SIZE);

					break;

				case M48T08_RAM_TYPE:

					RAM_battery_is_OK = Check_if_RAM_battery_is_OK();
					RAM_memory_is_OK = Check_if_RAM_memory_is_OK(M48T08_RAM_SIZE);

					break;

				case M48Z08_RAM_TYPE:

					RAM_battery_is_OK = Check_if_RAM_battery_is_OK();
					RAM_memory_is_OK = Check_if_RAM_memory_is_OK(M48Z08_RAM_SIZE);

					break;

				case S62256_RAM_TYPE:

					/* That RAM type is not battery-backed */
					RAM_battery_is_OK = FALSE;
					RAM_memory_is_OK = Check_if_RAM_memory_is_OK(S62256_RAM_SIZE);

					break;

				default:

					/* Unsupported RAM type */
					RAM_battery_is_OK = FALSE;
					RAM_memory_is_OK = FALSE;

					break;
			}

			module_detection_was_performed = 1;
		}

		/* Compose response */
		tx_response_buffer[CMD_INDEX]				= RAMTEST_COMMAND;
		tx_response_buffer[DETECT_INDEX]			= module_is_connected;
		tx_response_buffer[RAM_BATTERY_IS_OK_INDEX]	= RAM_battery_is_OK;
		tx_response_buffer[RAM_MEMORY_IS_OK_INDEX]	= RAM_memory_is_OK;

		/* Send response to PC */
		TX_frame(tx_response_buffer, RAMTEST_CMD_RESPONSE_LEN);

		BUSY_LED_OFF;
	}

	return;
}

void ControlRamClock(void)
{
	uint8_t execution_OK = TRUE;

	/* Check command length */
	if(rx_cmd_len == CONTROL_RAM_CLOCK_CMD_LEN)
	{
		BUSY_LED_ON;

		uint8_t ram_type		= rx_cmd_buffer[RAM_TYPE_INDEX];
		uint8_t ram_clock_cmd	= rx_cmd_buffer[RAM_CLOCK_CMD_INDEX];

		/* Perform test only if module is connected */
		if(module_is_connected == TRUE)
		{
			/* Check if type is correct */
			if((ram_type == M48T02_RAM_TYPE) || (ram_type == M48T08_RAM_TYPE))
			{
				switch(ram_clock_cmd)
				{
					case START_CLOCK_OSCILLATOR:

						/* Memory size is offset to clock */
						Start_RAM_clock_oscillator((ram_type == M48T02_RAM_TYPE) ? M48T02_RAM_SIZE : M48T08_RAM_SIZE);

						execution_OK = TRUE;

						break;

					case STOP_CLOCK_OSCILLATOR:

						Stop_RAM_clock_oscillator((ram_type == M48T02_RAM_TYPE) ? M48T02_RAM_SIZE : M48T08_RAM_SIZE);

						execution_OK = TRUE;

						break;

					case RESET_CLOCK:

						Reset_RAM_clock((ram_type == M48T02_RAM_TYPE) ? M48T02_RAM_SIZE : M48T08_RAM_SIZE);

						execution_OK = TRUE;

						break;

					default:

						execution_OK = FALSE;

						break;
				}
			}

			module_detection_was_performed = 1;
		}

		/* Compose response */
		tx_response_buffer[CMD_INDEX]				= CONTROL_RAM_CLOCK_COMMAND;
		tx_response_buffer[DETECT_INDEX]			= module_is_connected;
		tx_response_buffer[EXECUTION_OK_INDEX]		= execution_OK;

		/* Send response to PC */
		TX_frame(tx_response_buffer, CONTROL_RAM_CLOCK_CMD_RESPONSE_LEN);

		BUSY_LED_OFF;
	}

	return;
}

void GetRamClock(void)
{
	uint8_t clock_data_valid = TRUE;
	struct time_data clock_data;

	/* Check command length */
	if(rx_cmd_len == GET_RAM_CLOCK_CMD_LEN)
	{
		BUSY_LED_ON;

		uint8_t ram_type = rx_cmd_buffer[RAM_TYPE_INDEX];

		if(module_is_connected == TRUE)
		{
			/* Select correct RAM */
			switch(ram_type)
			{
				case M48T02_RAM_TYPE:

					Get_time_from_RAM_clock(M48T02_RAM_SIZE, &clock_data);

					/* Data OK */
					clock_data_valid = TRUE;

					break;

				case M48T08_RAM_TYPE:

					Get_time_from_RAM_clock(M48T08_RAM_SIZE, &clock_data);

					/* Data OK */
					clock_data_valid = TRUE;

					break;


				default:

					/* Unsupported RAM */
					clock_data_valid = FALSE;

					break;
			}
		}
		else
		{
			/* RAM adapter not connected at all */
			clock_data_valid = FALSE;
		}

		/* Compose response */
		tx_response_buffer[CMD_INDEX] 				= GET_RAM_CLOCK_COMMAND;
		tx_response_buffer[DETECT_INDEX]			= module_is_connected;
		tx_response_buffer[CLOCK_DATA_VALID_INDEX]	= clock_data_valid;

		if(clock_data_valid == TRUE)
		{
			memcpy(&tx_response_buffer[CLOCK_DATA_GET_DATA_INDEX], &clock_data, sizeof(clock_data));
		}
		else
		{
			/* Clear buffer if data is not valid */
			memset(&tx_response_buffer[CLOCK_DATA_GET_DATA_INDEX], 0x00, sizeof(clock_data));
		}

		/* Send response to PC */
		TX_frame(tx_response_buffer, GET_RAM_CLOCK_CMD_RESPONSE_LEN);

		BUSY_LED_OFF;
	}

	return;
}

void SetRamClock(void)
{
	uint8_t execution_OK = TRUE;
	struct time_data clock_data;

	/* Check command length */
	if(rx_cmd_len == SET_RAM_CLOCK_CMD_LEN)
	{
		BUSY_LED_ON;

		uint8_t ram_type		= rx_cmd_buffer[RAM_TYPE_INDEX];

		/* Copy data to clock data structure */
		memcpy(&clock_data, &rx_cmd_buffer[RAM_CLOCK_SET_DATA_INDEX], sizeof(clock_data));

		if(module_is_connected == TRUE)
		{
			/* Select correct RAM */
			switch(ram_type)
			{
				case M48T02_RAM_TYPE:

					Set_time_in_RAM_clock(M48T02_RAM_SIZE, &clock_data);

					/* Executed OK */
					execution_OK = TRUE;

					break;

				case M48T08_RAM_TYPE:

					Set_time_in_RAM_clock(M48T08_RAM_SIZE, &clock_data);

					/* Executed OK */
					execution_OK = TRUE;

					break;


				default:

					/* Unsupported RAM */
					execution_OK = FALSE;

					break;
			}
		}
		else
		{
			/* RAM adapter not connected at all */
			execution_OK = FALSE;
		}

		/* Compose response */
		tx_response_buffer[CMD_INDEX] 			= SET_RAM_CLOCK_COMMAND;
		tx_response_buffer[DETECT_INDEX]		= module_is_connected;
		tx_response_buffer[EXECUTION_OK_INDEX]	= execution_OK;

		/* Send response to PC */
		TX_frame(tx_response_buffer, SET_RAM_CLOCK_CMD_RESPONSE_LEN);

		BUSY_LED_OFF;
	}

	return;
}



inline uint8_t Check_8K_ROM(void)
{
	uint8_t ROM_is_present = ROM_NOT_PRESENT;

	/* Check if ROM is present */
	if(Check_if_ROM_is_present(ROM_SIZE_8K) == TRUE)
	{
		/* ROM is present */

		/* Check if it is empty */
		if(Check_if_ROM_is_empty(ROM_SIZE_8K) == TRUE)
		{
			/* ROM is empty, mark as not present */
			ROM_is_present = ROM_NOT_PRESENT;
		}
		else
		{
			/* Not empty, mark as present */
			ROM_is_present = ROM_IS_PRESENT;
		}
	}
	else
	{
		/* ROM is not present */
		ROM_is_present = ROM_NOT_PRESENT;
	}

	return ROM_is_present;
}

inline uint8_t Check_32K_ROM(void)
{
	uint8_t ROM_is_present = ROM_NOT_PRESENT;

	/* Check if ROM is present */
	if(Check_if_ROM_is_present(ROM_SIZE_32K) == TRUE)
	{
		/* ROM is present */

		/* Check if it is empty */
		if(Check_if_ROM_is_empty(ROM_SIZE_32K) == TRUE)
		{
			/* ROM is empty, mark as not present */
			ROM_is_present = ROM_NOT_PRESENT;
		}
		else
		{
			/* Not empty, mark as present */
			ROM_is_present = ROM_IS_PRESENT;
		}
	}
	else
	{
		/* ROM is not present */
		ROM_is_present = ROM_NOT_PRESENT;
	}

	return ROM_is_present;
}

inline uint8_t Check_64K_ROMs(void)
{
	uint8_t ROM_is_present = ROM_NOT_PRESENT;

	/* Check high bank */
	SET_A15_TO_HIGH;

	if(Check_32K_ROM() == ROM_IS_PRESENT)
	{
		/* High bank is present */

		/* ROM is present */
		ROM_is_present = ROM_IS_PRESENT;
	}
	else
	{
		/* High bank is not present (very rare scenario) */

		/* Check low bank */
		SET_A15_TO_LOW;

		if(Check_32K_ROM() == ROM_IS_PRESENT)
		{
			/* Low bank is present */

			/* So, ROM is present */
			ROM_is_present = ROM_IS_PRESENT;
		}
		else
		{
			/* Neither high nor low bank are present */
			ROM_is_present = ROM_NOT_PRESENT;
		}
	}

	/* Set back to high bank */
	SET_A15_TO_HIGH;

	return ROM_is_present;
}

inline uint8_t Select_correct_bank_for_A_ROM(uint8_t block_number, uint8_t *block_to_read)
{
	uint8_t data_valid = TRUE;

	/* Is this low bank ? */
	if((block_number >= BLOCK_NUMBER_LOW_BANK_MIN_ROM_A) && (block_number <= BLOCK_NUMBER_LOW_BANK_MAX_ROM_A))
	{
		/* A15 is dont care for that ROM */
		SET_A15_TO_HIGH;

		/* Range OK */
		data_valid = TRUE;
	}
	else
	{
		/* Default */
		SET_A15_TO_HIGH;

		/* Wrong range, data invalid */
		data_valid = FALSE;
	}

	/* For ROMA, pass */
	*block_to_read = block_number;

	return data_valid;
}

inline uint8_t Select_correct_bank_for_B_and_C_ROMs(uint8_t block_number, uint8_t *block_to_read)
{
	uint8_t data_valid = TRUE;

	/* Is this low bank ? */
	if((block_number >= BLOCK_NUMBER_LOW_BANK_MIN_ROM_BC) && (block_number <= BLOCK_NUMBER_LOW_BANK_MAX_ROM_BC))
	{
		/* Select low 32K bank */
		SET_A15_TO_LOW;

		/* Low bank */
		*block_to_read = block_number;
	}
	else if((block_number >= BLOCK_NUMBER_HIGH_BANK_MIN_ROM_BC) && (block_number <= BLOCK_NUMBER_HIGH_BANK_MAX_ROM_BC))
	{
		/* Select high 32K bank */
		SET_A15_TO_HIGH;

		/* High, bank, address overlap */
		*block_to_read = block_number - BLOCK_NUMBER_HIGH_BANK_MIN_ROM_BC;
	}
	else
	{
		/* Default */
		SET_A15_TO_HIGH;
		*block_to_read = 0;

		/* Wrong range, data invalid */
		data_valid = FALSE;
	}

	return data_valid;
}

inline void Clear_ROM_info(void)
{
	ROM_A_is_present = ROM_NOT_PRESENT;
	ROM_B_is_present = ROM_NOT_PRESENT;
	ROM_C_is_present = ROM_NOT_PRESENT;

	/* That flag will be set if ROM is connected and detection was performed */
	module_detection_was_performed = FALSE;

	return;
}

ISR(ISR_TIMER_VECTOR)
{
	static uint8_t toggle_led_counter = 0;

	if(IS_ROM_MODULE_PRESENT)
	{
		/* Set connected flag */
		module_is_connected = TRUE;

		/* Set detect LED */
		DETECT_LED_ON;

		/* Clear counter */
		toggle_led_counter = 0;
	}
	else
	{
		/* Reset connected flag */
		module_is_connected = FALSE;

		/* Reset ROM detection flags */
		Clear_ROM_info();

		/* Blink detect LED */
		toggle_led_counter++;
		if(toggle_led_counter >= DETECT_LED_COUNTER_MAX)
		{
			toggle_led_counter = 0;

			DETECT_LED_TOGGLE;
		}
	}

	return;
}

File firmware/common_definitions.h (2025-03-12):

/* 
Project name:	FLT/ART/CU1 ROM Reader
Author: 		trwgQ26xxx
Date:			26.06.2024
Target MCUs:	ATmega64/ATmega64L/ATmega64A/ATmega128/ATmega128L/ATmega128A
Compiler:		AVR-GCC version 7.3.0
*/

#ifndef _COMMON_DEFINITIONS_H
#define _COMMON_DEFINITIONS_H

/* UART parameters */
#define BAUDRATE							115200UL

/* LED blinking parameters */
#define TMR_PERIOD							20	//ms
#define DETECT_LED_PERIOD					200	//ms

#define DETECT_LED_COUNTER_MAX				(DETECT_LED_PERIOD / TMR_PERIOD)

/* ROM sizes */
#define ROM_NOT_PRESENT						0
#define ROM_IS_PRESENT						1
#define RAM_SIZE_2K							2
#define ROM_SIZE_8K							8
#define ROM_SIZE_32K						32
#define ROM_SIZE_64K						64

/* ROM types */
#define ROM_TYPE_A							'A'
#define ROM_TYPE_B							'B'
#define ROM_TYPE_C							'C'

/* Commands */
#define NO_COMMAND							0
#define DETECT_COMMAND						't'
#define READ_COMMAND						'd'
#define RAMTEST_COMMAND						'r'
#define CONTROL_RAM_CLOCK_COMMAND			'c'
#define GET_RAM_CLOCK_COMMAND				'g'
#define SET_RAM_CLOCK_COMMAND				's'

/* RAM types for ram-test */
#define M48Z02_RAM_TYPE						'z'
#define M48T02_RAM_TYPE						't'
#define M48Z08_RAM_TYPE						'Z'
#define M48T08_RAM_TYPE						'T'
#define S62256_RAM_TYPE						'6'

#define START_CLOCK_OSCILLATOR				'e'
#define STOP_CLOCK_OSCILLATOR				'd'
#define RESET_CLOCK							'r'

/* ROM chunks parameters */
#define SINGLE_BLOCK_SIZE					512
#define BLOCK_NUMBER_LOW_BANK_MIN_ROM_A		0
#define BLOCK_NUMBER_LOW_BANK_MAX_ROM_A		15
#define BLOCK_NUMBER_LOW_BANK_MIN_ROM_BC	0
#define BLOCK_NUMBER_LOW_BANK_MAX_ROM_BC	63
#define BLOCK_NUMBER_HIGH_BANK_MIN_ROM_BC	64
#define BLOCK_NUMBER_HIGH_BANK_MAX_ROM_BC	127

/* Transmission parameters */
#define TX_BUFFER_MAX_LEN					514

#define RX_CMD_BUFFER_MAX_LEN				16
#define CMD_FIELD_SIZE						1	//CMD (1 byte)
#define CRC_FIELD_SIZE						2	//CRC16 (2 bytes)
#define RX_CMD_MIN_LEN						(CMD_FIELD_SIZE + CRC_FIELD_SIZE)

/* RX frames */
#define CMD_INDEX							0
#define ROM_SEL_INDEX						1
#define RAM_TYPE_INDEX						1
#define BLOCK_NUMBER_INDEX					2
#define RAM_CLOCK_CMD_INDEX					2
#define RAM_CLOCK_SET_DATA_INDEX			2

#define DETECT_CMD_LEN						1
#define READ_CMD_LEN						3
#define RAMTEST_CMD_LEN						2
#define CONTROL_RAM_CLOCK_CMD_LEN			3
#define GET_RAM_CLOCK_CMD_LEN				2
#define SET_RAM_CLOCK_CMD_LEN				9

/* TX frames */

/* Detect TX frame */
#define DETECT_CMD_RESPONSE_LEN				5
#define DETECT_INDEX						1
#define A_SIZE_INDEX						2
#define B_SIZE_INDEX						3
#define C_SIZE_INDEX						4

/* Read TX frame */
#define READ_CMD_RESPONSE_LEN				514
#define DATA_VALID_INDEX					1
#define DATA_INDEX							2

/* RAM test TX frame */
#define RAMTEST_CMD_RESPONSE_LEN			4
#define RAM_BATTERY_IS_OK_INDEX				2
#define RAM_MEMORY_IS_OK_INDEX				3

/* Control RAM clock command TX frame */
#define CONTROL_RAM_CLOCK_CMD_RESPONSE_LEN	3
#define EXECUTION_OK_INDEX					2

/* Get RAM clock data TX frame */
#define GET_RAM_CLOCK_CMD_RESPONSE_LEN		10
#define CLOCK_DATA_VALID_INDEX				2
#define CLOCK_DATA_GET_DATA_INDEX			3

/* Set RAM clock data TX frame */
#define SET_RAM_CLOCK_CMD_RESPONSE_LEN		3

/* RAM sizes for RAM test */
#define M48Z02_RAM_SIZE						0x800
#define M48T02_RAM_SIZE						0x7F8
#define M48Z08_RAM_SIZE						0x2000
#define M48T08_RAM_SIZE						0x1FF8
#define S62256_RAM_SIZE						0x8000

/* Constant definitions */
#define TRUE								1
#define FALSE								0

#endif

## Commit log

2024-04-20 PCB project added
    [ROM_reader.kicad_pcb, ROM_reader.kicad_sch]
2024-08-24 RAM adapter PCB project for RAM testing added
    [RAM_adapter.kicad_pcb, RAM_adapter.kicad_sch]
2025-01-21 Revised RAM adapter PCB
    [RAM_adapter.kicad_pcb, RAM_adapter.kicad_sch]
2025-01-21 Datasheets for M48x02 battery-backed SRAMs added
2025-01-21 ROM reader project PCBs updated
    [RAM_adapter.kicad_pcb, RAM_adapter.kicad_sch, ROM_reader.kicad_pcb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]
2025-01-21 ADC disabled. Procedures removed as were not functional. Unused pins configured as inputs with pull-ups
2025-01-22 Minor changes in text placement on PCB, comments. Revision updated to B
    [RAM_adapter.kicad_pcb, RAM_adapter.kicad_sch, ROM_reader.kicad_pcb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]
2025-02-05 PCB project update: pull-up resistors added for D0-D7 data lines
    [ROM_reader.kicad_pcb, ROM_reader.kicad_sch]
2025-02-10 Minor updates
    [ROM_reader.kicad_pcb, ROM_reader.kicad_sch]
2025-03-01 UART baudrate increased from 57600 to 115200
2025-03-12 Added script to configure fuse bits, WDTON fuse added
2025-03-18 Reintroduced the system call, as its absence caused missing colors on the Windows console
    [reader.py]
2026-08-02 miniUSB socket replaced with USB C socket. PCB now at revision D
